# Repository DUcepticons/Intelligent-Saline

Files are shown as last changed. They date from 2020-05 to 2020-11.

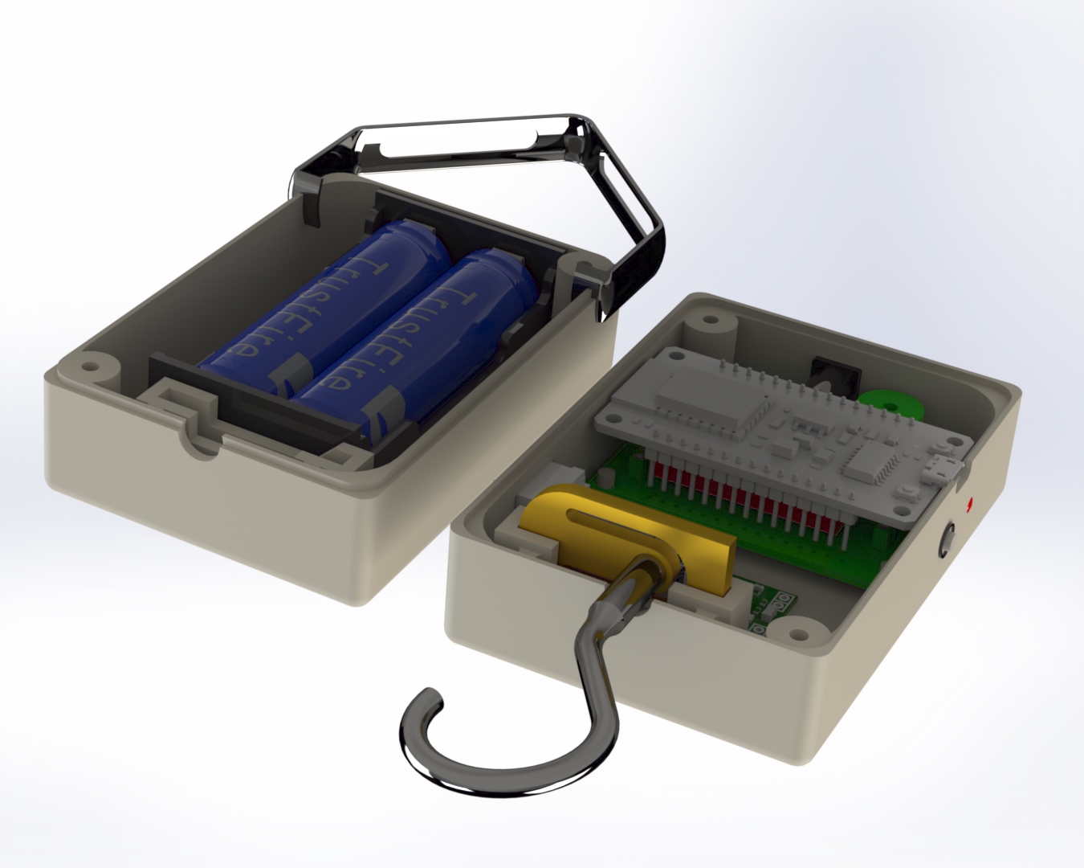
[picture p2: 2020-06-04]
Device Images/Inside_designed.jpg

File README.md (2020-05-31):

# Intelligent-Saline

cmd>> ipconfig
See the server ip address (192.168.0.xxx)

Edit those two NodeMCU code lines:
const char *host = "192.168.0.xxx"; 
String Link = "http://192.168.0.xxx:8000/receive/";

Instruction to run server (USE IP OTHERWISE NODEMCU DATA WON'T BE RECEIVED): python manage.py runserver 192.168.0.xxx:8000
In a browser go to - 192.168.0.xxx:8000
Voilla!! Here you go....

Existing login: 
ducepticons
saline123

To Create a new user: python manage.py createsuperuser

django 3.0.3

To use database in command shell:
going to command shell>> python manage.py shell
>> from main.models import patient
>> object = patient.objects.all()

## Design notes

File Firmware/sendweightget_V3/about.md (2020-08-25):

V3 is updated with external flow blocker.

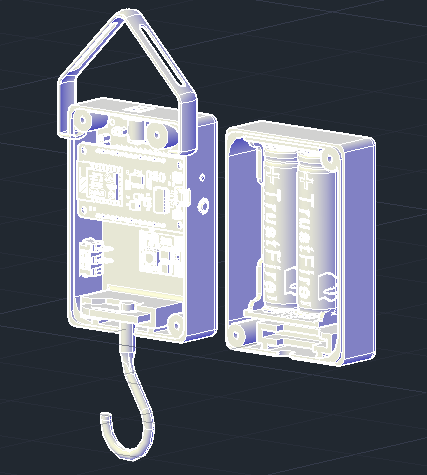
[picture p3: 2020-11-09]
Autocad Compatible/Autocad Images/Product/Device Only/conceptual.png

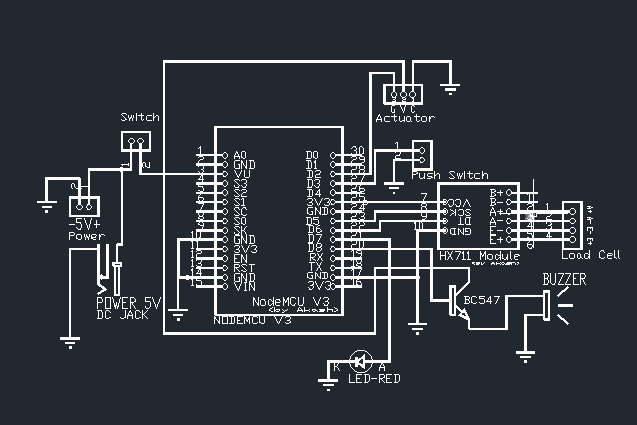
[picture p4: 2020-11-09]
Autocad Compatible/Autocad Images/PCB/schematic.png

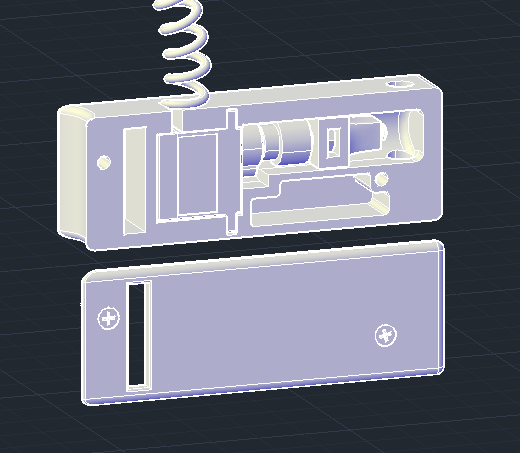
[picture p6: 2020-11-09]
Autocad Compatible/Autocad Images/Product/Flow Controller/Conceptual.png

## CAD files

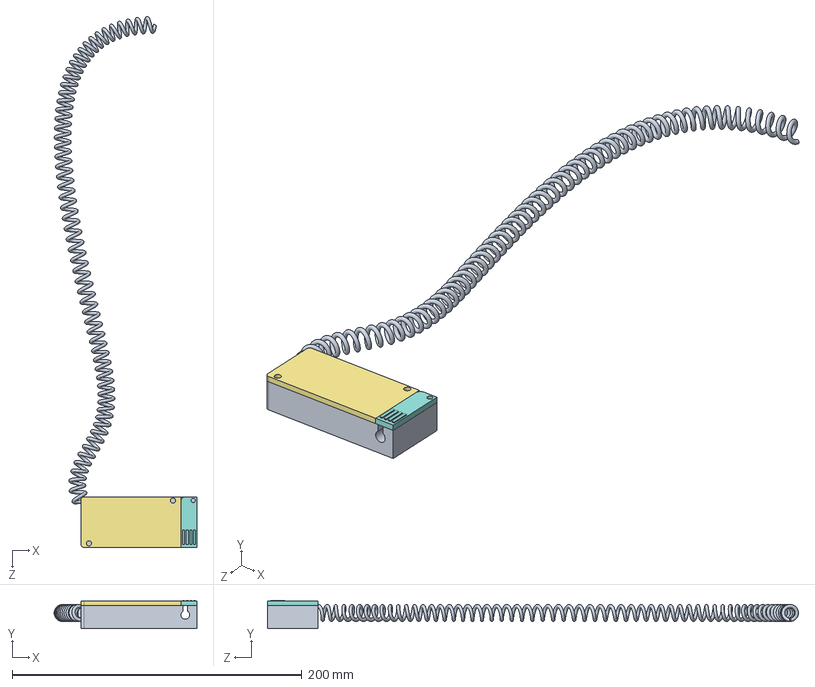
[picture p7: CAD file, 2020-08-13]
Product Design/V2/flow blocker/Version1 Flow blocker/Flow blocker assembly.SLDASM
98.6 x 19.5 x 366.6 mm
flow blocker
Servo-MG90S
pan cross head_am
hex nut style 1_am
servo bolt connector
press
upper cover
pipe cover
Spiral-cord

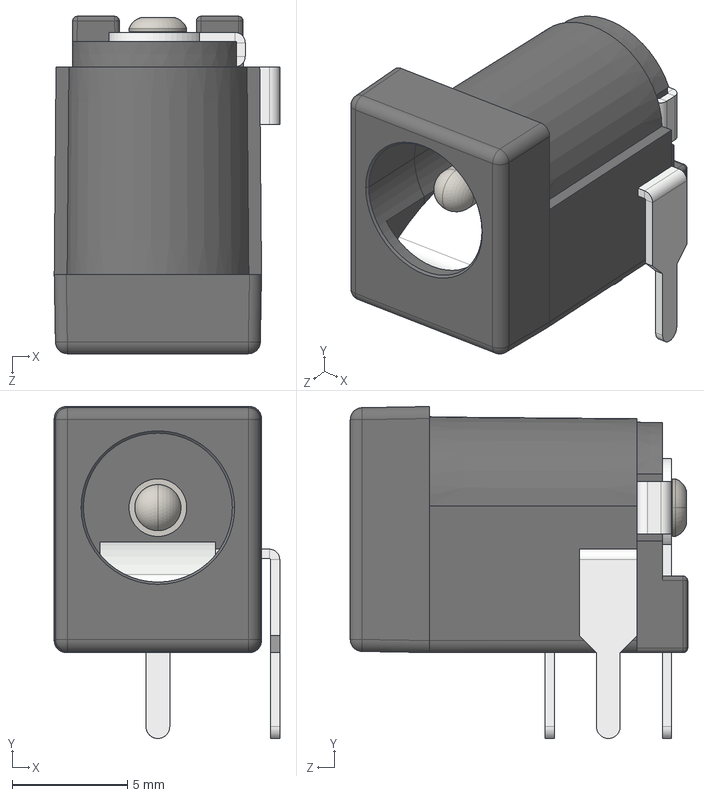
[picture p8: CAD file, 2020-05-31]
Product Design/V2/dc-power-jack-5-5mm-x-2-1mm-2-54mm-pitch-1.snapshot.5/DC Power Jack 5.5mm x 2.1mm.STEP
9.77 x 14.4 x 14.6 mm

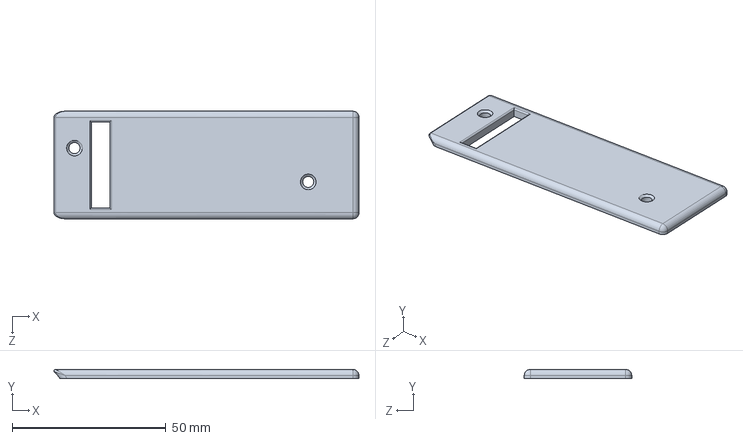
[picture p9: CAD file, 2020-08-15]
Product Design/V2/flow blocker/upper cover.SLDPRT
99.2 x 3.00 x 35.0 mm

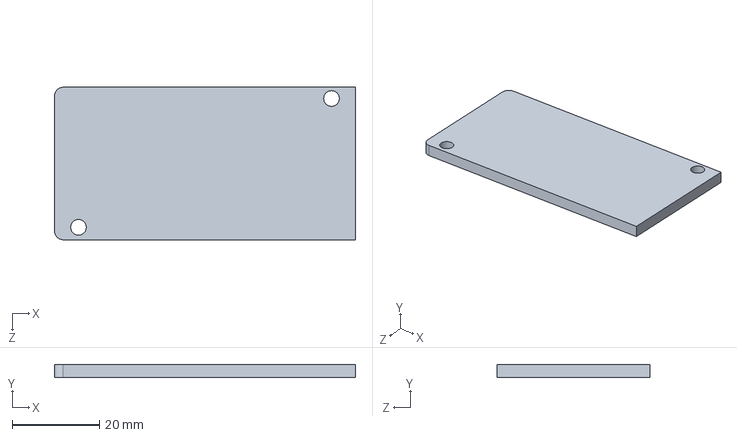
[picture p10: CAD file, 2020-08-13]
Product Design/V2/flow blocker/Version1 Flow blocker/upper cover.SLDPRT
69.0 x 3.00 x 35.0 mm

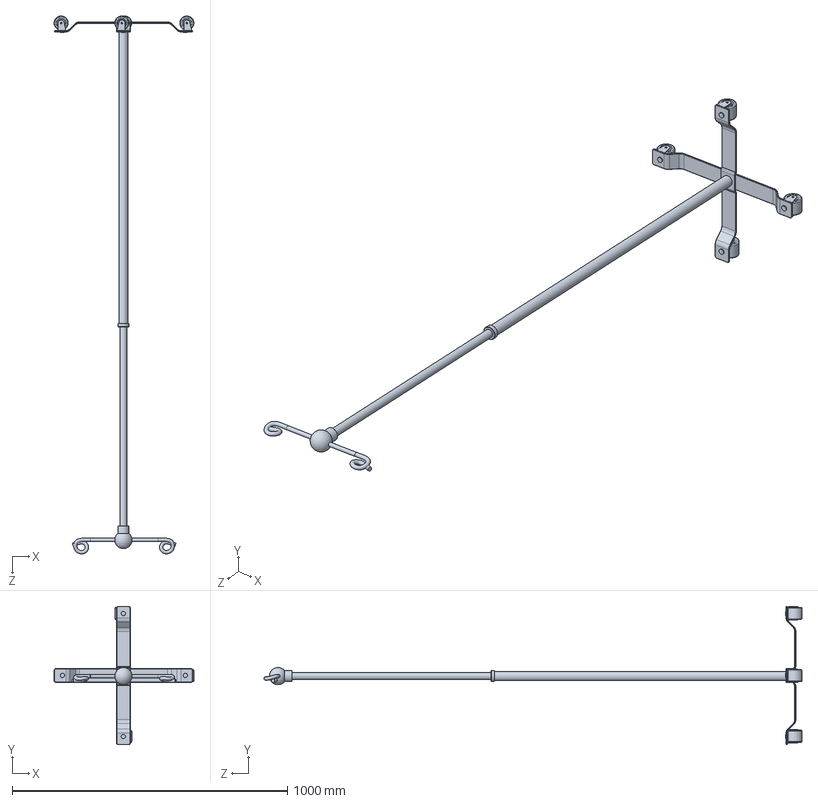
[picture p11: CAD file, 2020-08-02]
Product Design/V2/IV Stand.SLDPRT
508.6 x 502.9 x 1955.7 mm

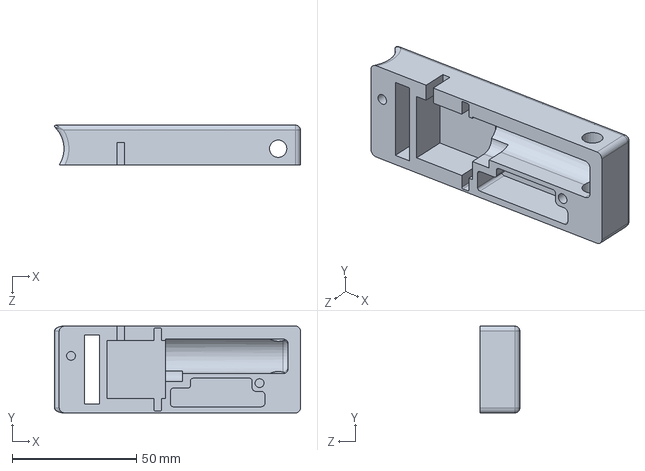
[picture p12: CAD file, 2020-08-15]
Product Design/V2/flow blocker/flow blocker.SLDPRT
99.2 x 35.0 x 16.0 mm

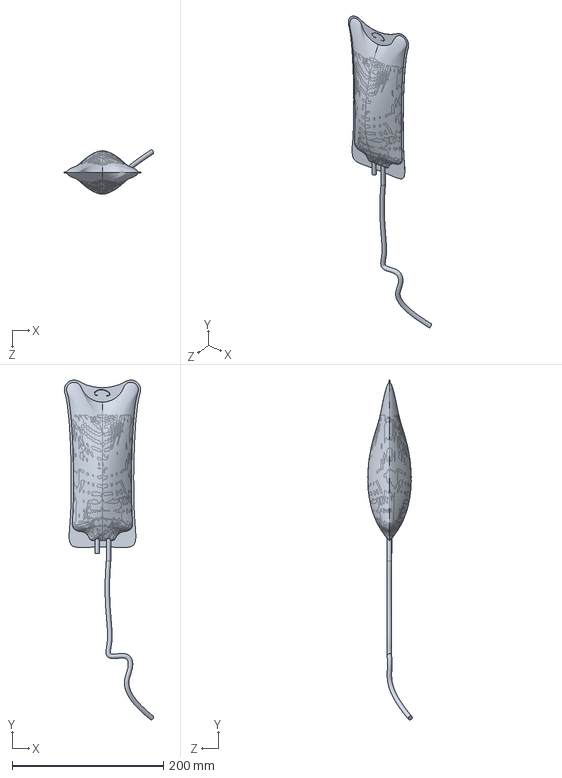
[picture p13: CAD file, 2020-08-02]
Product Design/V2/saline bag.SLDPRT
118.3 x 449.9 x 58.9 mm

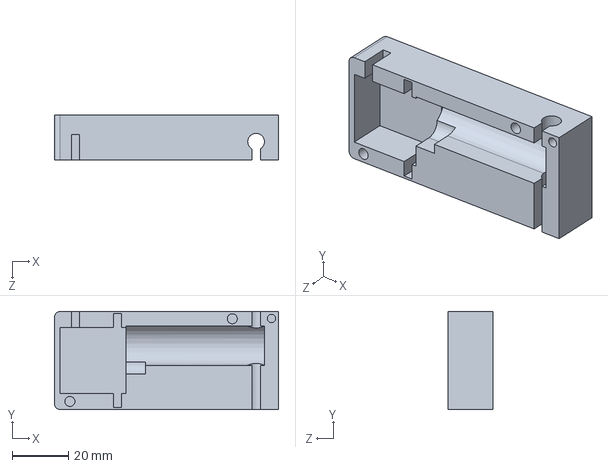
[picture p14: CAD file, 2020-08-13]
Product Design/V2/flow blocker/Version1 Flow blocker/flow blocker.SLDPRT
80.0 x 35.0 x 16.0 mm

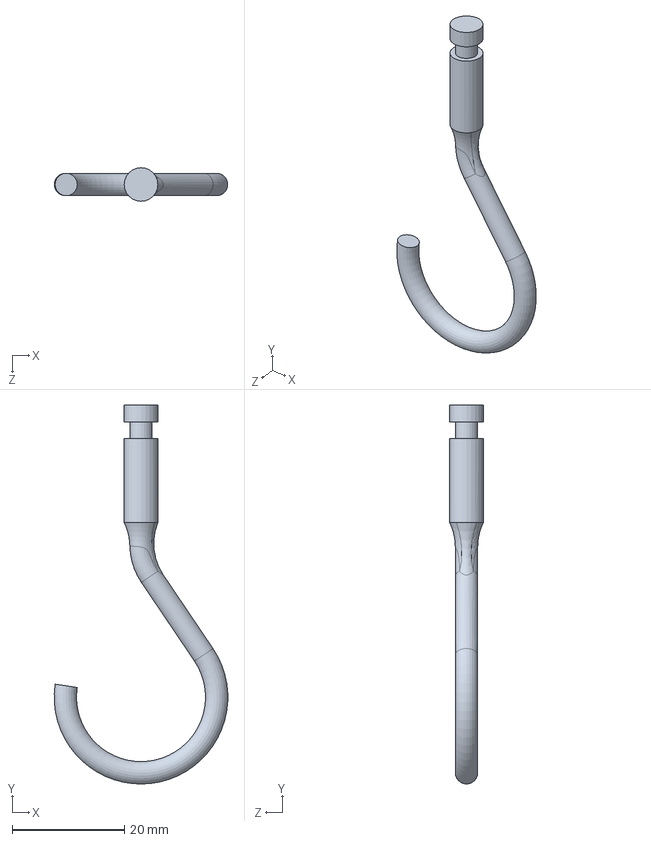
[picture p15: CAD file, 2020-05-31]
Product Design/V2/hook.SLDPRT
31.0 x 67.6 x 6.00 mm

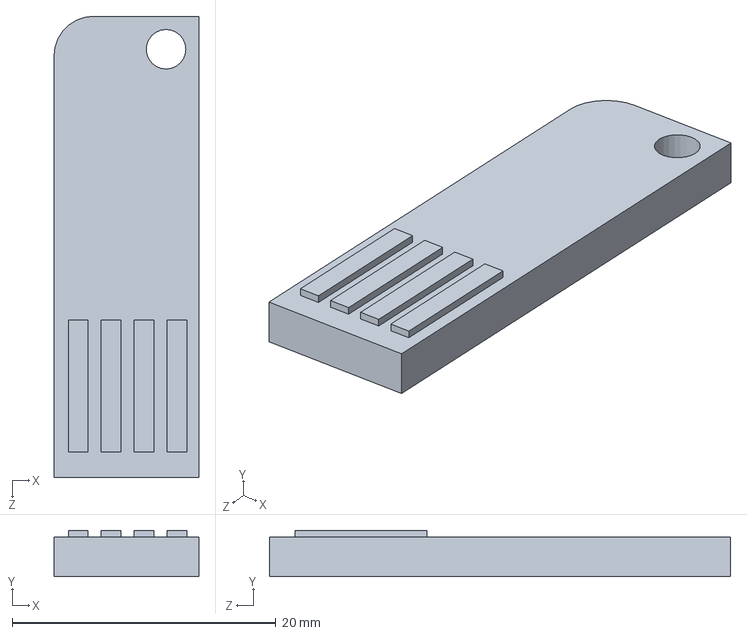
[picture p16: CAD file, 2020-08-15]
Product Design/V2/flow blocker/pipe cover(not used).SLDPRT
11.0 x 3.50 x 35.0 mm

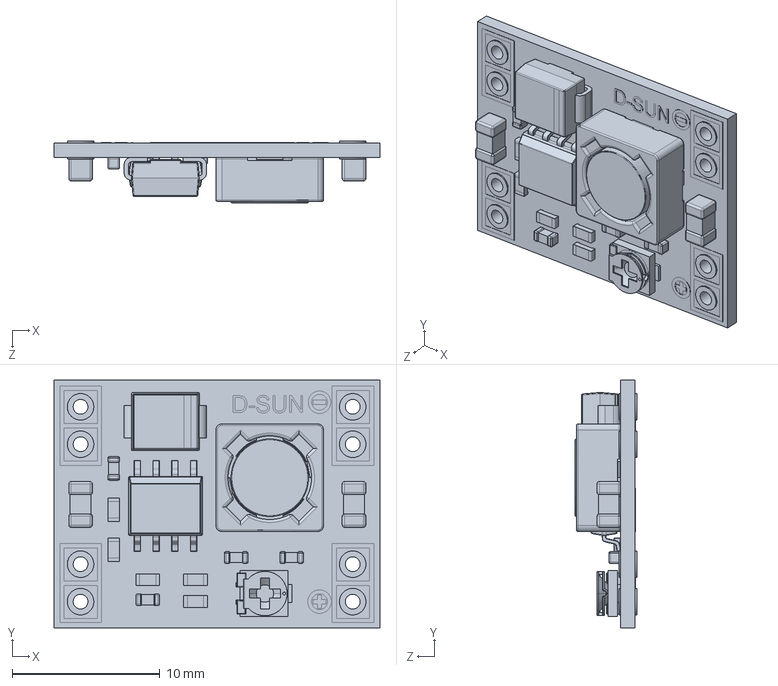
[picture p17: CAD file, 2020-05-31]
Product Design/V2/voltage-regulator.SLDPRT
22.1 x 16.8 x 4.19 mm

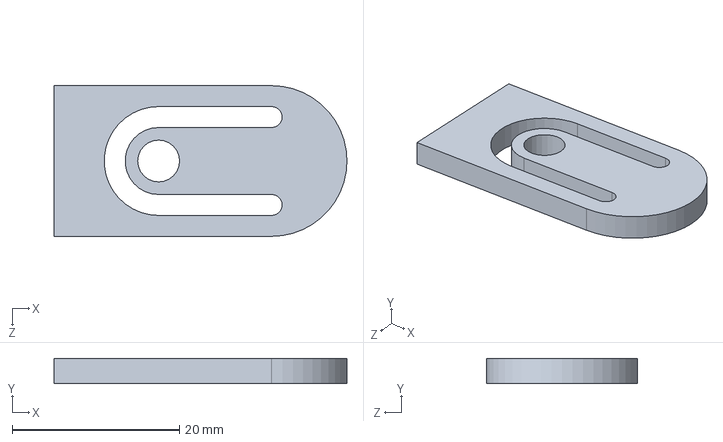
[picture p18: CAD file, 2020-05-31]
Product Design/V2/load cell.SLDPRT
35.0 x 3.00 x 18.0 mm

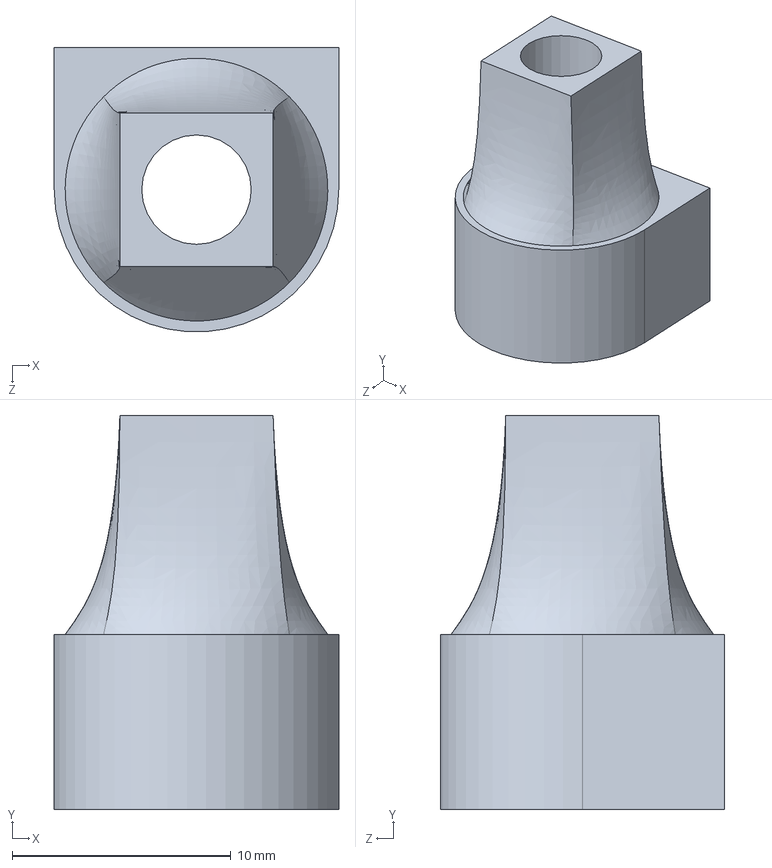
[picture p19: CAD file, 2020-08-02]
Product Design/V2/flow blocker/Version1 Flow blocker/press.SLDPRT
13.0 x 18.0 x 13.0 mm

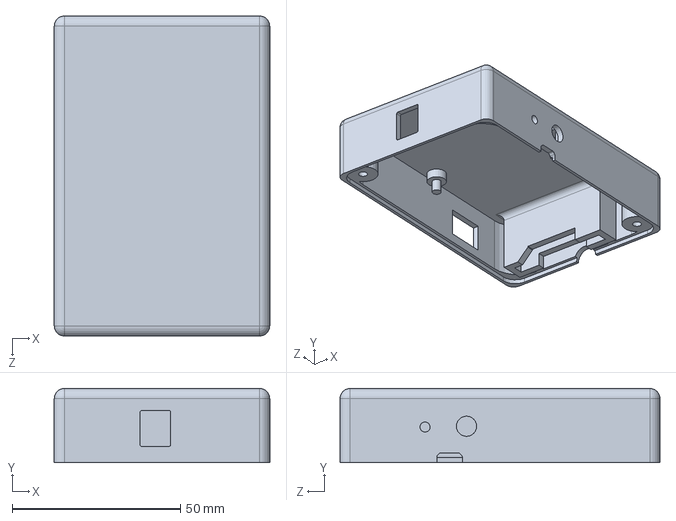
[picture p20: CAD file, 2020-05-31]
Product Design/V2/upper_body.SLDPRT
64.0 x 22.0 x 95.0 mm

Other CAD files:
Autocad Compatible/PCB Design/schematic.dwg
Autocad Compatible/PCB Design/pcb_bottomLayer.dwg
Autocad Compatible/PCB Design/pcb_topLayer.dwg
Product Design/V2/flow blocker/Version1 Flow blocker/pipe cover.SLDPRT
Product Design/V1/18650-retainers-1.snapshot.4/18650 1x Holder - Compressed.stp
Product Design/V1/18650-retainers-1.snapshot.4/18650 1x Holder.stp
Product Design/V1/18650-retainers-1.snapshot.4/BC2-3AE.stp
Product Design/V1/18650-retainers-1.snapshot.4/BK-18650-PC2.stp
Product Design/V1/18650-retainers-1.snapshot.4/BK-18650-PC4.stp
Product Design/V1/18650-retainers-1.snapshot.4/BK-18650-PC6.stp
Product Design/V1/18650-retainers-1.snapshot.4/BK-18650-PC8.stp
Product Design/V1/18650-retainers-1.snapshot.4/keystone_1042-Mod.stp
Product Design/V1/2-Pin ON-OFF Switch.SLDPRT
Product Design/V1/TR18650.SLDPRT
Product Design/V1/batt-case-18650.SLDPRT
Product Design/V1/hook.SLDPRT
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

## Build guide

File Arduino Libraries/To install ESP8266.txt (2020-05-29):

1 .
Arduino >> File >> Preferences
In additional board manager URLs pase : http://arduino.esp8266.com/stable/package_esp8266com_index.json

2.
Tools >> Board >> Board Manager >> search "esp8266" >> install (suitable one)

3.
Tools >> Select Board >> NodeMCU 1.0

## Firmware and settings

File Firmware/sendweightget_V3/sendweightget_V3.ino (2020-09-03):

#include <ESP8266WiFi.h>
#include <WiFiClient.h> 
#include <ESP8266WebServer.h>
#include <ESP8266HTTPClient.h>
#include <HX711.h>
#include<Servo.h>
#include <EEPROM.h>

String DEV_ID = "DEV00002";                                   //Input the device id here
const char *ssid = "DUcepticons";                                 //ENTER YOUR WIFI SETTINGS
const char *password = "webpass321";

//Web/Server address to read/write from 
const char *host = "192.168.0.102"; 
String Link = "http://192.168.0.102:8000/receive/";

char eepromStatus;
int EEPROMaddress = 0; //Reading from address 0x00

int critical_value = 15;
int very_critical_value = 10;
int flow_block_value = 5;
const int SCALE_DOUT_PIN = D6;
const int SCALE_SCK_PIN = D5;
const int Buzzer = D8;
const int LED = D7;
const int Push_button = D3;
const int ServoPin = D2;
int push_button_state = 0;

int flag = 0;
float initial_saline_weight;
float weight = 0;
int count = 0;

int sendPercentage=100;
int previous_sendPercentage =0;
String payload;
float full_bag_weight;
float package_weight;

String previousOnOff_status = "1";

void buzzer_alarm(int rate);        // input how many times to beep in a second
void buzzer_stop();
void buzzer_indication(int times, int Delay);  //input how many times to beep buzzer and stop

HX711 scale(SCALE_DOUT_PIN, SCALE_SCK_PIN);
void Lock(int Speed, int Delay);//Flow block function
void Open(int Speed, int Delay);//Flow open function

Servo servo;      // Flow blockeer servo declare
//=======================================================================
//                    Power on setup
//=======================================================================

void setup() {
  Serial.begin(115200);
  EEPROM.begin(512);  //Initialize EEPROM
  scale.set_scale(45);// <- set here calibration factor!!!
  scale.tare();
  pinMode(Buzzer,OUTPUT);
  pinMode(LED,OUTPUT);
  pinMode(Push_button,INPUT_PULLUP);
  
  digitalWrite(Buzzer,HIGH);
  digitalWrite(LED,HIGH);
  delay(1000);
  digitalWrite(Buzzer,LOW);
  digitalWrite(LED,LOW);

   
  weight = scale.get_units(1);
  float new_weight = 0;
  int not_ok = 1;
  

  //Wait and slow beepiing untill saline is On device hook
  Serial.println("Waiting for saline.....");
 
  while(true)
  {
    new_weight = scale.get_units(1);
    if(abs(new_weight-weight) >250)break;   //250 depends on variety of saline pack can be used in this device
    buzzer_indication(1,1000);
    weight = new_weight;
  }
Serial.println("Saline on device");
weight = 0;

Serial.println("Saline recognizing...");
//automatic weight recognition
  while(true)
  {
    new_weight = abs(scale.get_units(1));
    Serial.println(new_weight);
    if(abs(new_weight-weight) <10 && count>=15)
    {
      if(new_weight > 300 && new_weight < 800)
      {
          initial_saline_weight = 500;          
          //not_ok = 0;
          break;
      }
      else if(new_weight > 800 && new_weight < 1500)
      {
          initial_saline_weight = 1000;
          //not_ok = 0;
          break;
      }
    }
    weight = new_weight;
    count++;
  }
  count=0;
Serial.println("Saline recognized as "+ String(initial_saline_weight));
  


  WiFi.mode(WIFI_OFF);        //Prevents reconnection issue (taking too long to connect)
  delay(1000);
  WiFi.mode(WIFI_STA);        //This line hides the viewing of ESP as wifi hotspot
  
  WiFi.begin(ssid, password);     //Connect to your WiFi router
  Serial.println("");

  Serial.print("Connecting");
  // Wait for connection
  while (WiFi.status() != WL_CONNECTED) {
    delay(300);
    flag ^= 1;
    digitalWrite(Buzzer,flag);
    Serial.print(".");
  }

  //If connection successful show IP address in serial monitor
  Serial.println("");
  Serial.print("Connected to ");
  Serial.println(ssid);
  Serial.print("IP address: ");
  Serial.println(WiFi.localIP());  //IP address assigned to your ESP


  full_bag_weight = abs(scale.get_units(1));
  package_weight = abs(full_bag_weight - initial_saline_weight);
  Serial.println("full_bag_weight: "+ String(full_bag_weight));
  Serial.println("package_weight: "+ String(package_weight));
  buzzer_stop();

  servo.attach(ServoPin);

  char eepromStatus = EEPROM.read(EEPROMaddress);
  
//if it was previously blocked, turn it on
  if (eepromStatus == '1'){
    Open(110, 4500);
    Serial.println("Saline flow Open...");
    EEPROM.write(EEPROMaddress, '0');    //Write character 0, meaning flow is turned on   
  }
}

//=======================================================================
//                    Main Program Loop
//=======================================================================




void loop() {

  weight = abs(scale.get_units(1)) - package_weight;
  Serial.println("Weight: "+ String(weight, 2));
  
  HTTPClient http;    //Declare object of class HTTPClient

 //GET Data
  
  sendPercentage= (weight/initial_saline_weight)*100 ;
  
  //Keeping in range of 0-100
  if(sendPercentage<0)sendPercentage=0;
  if(sendPercentage>100)sendPercentage=100;
  
  Serial.println(sendPercentage);

  String postData = DEV_ID + "," + String(sendPercentage);
  Serial.print(postData);
  Serial.print(Link);
  http.begin(Link);     //Specify request destination
  
  int httpCode = http.POST(postData);            //Send the request
  payload = http.getString();    //Get the response payload  //returns two digit value(ex. 50/51/60/61) First value for mute button(6=mute pressed, 5= default), 2nd value for saline on/off button(1=ON, 0=OFF)

  Serial.println(httpCode);   //Print HTTP return code
  Serial.println("payload" + payload);    //Print request response payload
  http.end();  //Close connection

//==========================================
//Flow ON/OFF function
//if toggled OFF
if((String)payload[1] == "0" && previousOnOff_status != (String)payload[1]){
  Lock(70, 4500);
  Serial.println("Saline flow Blocked!!!");
  eepromStatus = '1';
}
//if toggled ON
if((String)payload[1] == "1" && previousOnOff_status != (String)payload[1]){
  Open(110, 4500);
  Serial.println("Saline flow Open...");
  eepromStatus = '0';
}
previousOnOff_status = (String)payload[1];

/*
//debugging
if (sendPercentage <=critical_value && very_critical_value<sendPercentage)
{
  Serial.println("State : Critical");
}
else if (sendPercentage <=very_critical_value)
{
  Serial.println("State : Very Critical");
}
else
{
  Serial.println("State : Normal");
}
*/

//push_button_state change for entering 1-10%zone from 11-20%zone
if ((previous_sendPercentage <=critical_value  && previous_sendPercentage >very_critical_value) && (sendPercentage<=very_critical_value))
{
  push_button_state = 0;
}
previous_sendPercentage=sendPercentage;


//Push button read
  int button = digitalRead(Push_button);    // it reads 0 for press, 1 otherwise
  if (button == 0)Serial.println("button pressed");
  if((sendPercentage <= critical_value) && (button == 0 || (String)payload[0] == "6"))push_button_state = 1;   //when percentage under critical and mute button pressed
  //Serial.println(push_button_state);                                                              //payload returns 6 if mute button pressed
  Serial.println("\n\n");

  
//critical and very_critical saline level indication
  if (push_button_state == 0)
  {
    count++;
    if(sendPercentage <= critical_value  && very_critical_value < sendPercentage  && count>  6)
      {
        buzzer_indication(1,500);
        count = 0;
      }
    else if(sendPercentage <= very_critical_value  && count>  4)
      {
        buzzer_indication(3,175);
        count = 0;
      }
  }
if (sendPercentage >=critical_value)
{
  delay(1000);
  push_button_state = 0;
}

//flow block whenever percentage under flow_block_value
if (sendPercentage <= flow_block_value && eepromStatus != '1'){
   //if percentage<= flow_block_value and if flow was not blocked previously
  digitalWrite(Buzzer,HIGH);
  digitalWrite(LED,HIGH);
  Lock(70, 4500);
  Serial.println("Saline flow Blocked!!!"); 
  digitalWrite(Buzzer,LOW );
  digitalWrite(LED,LOW );
  EEPROM.write(EEPROMaddress, '1');    //Write character 1, meaning flow is blocked

}
  
}
//=======================================================================


void buzzer_alarm(int rate){
  digitalWrite(Buzzer,HIGH);
  delay(500/rate);
  digitalWrite(Buzzer,LOW );
  delay(500/rate);
}

void buzzer_stop(){
 digitalWrite(Buzzer,LOW );
}
void buzzer_indication(int times, int Delay){
  for( int i=0;i<times;i++)
  {
    digitalWrite(Buzzer,HIGH);
    digitalWrite(LED,HIGH);
    delay(Delay);
    digitalWrite(Buzzer,LOW );
    digitalWrite(LED,LOW );
    delay(Delay);
  }
}

//Flow block function
void Open(int Speed, int Delay){
  //When speed==90;stop
  //When speed>90;clockwise
  //When speed<90;anticlockwise
  servo.write(Speed);
  delay(Delay);
  servo.write(90);
}

//Flow open function
void Lock(int Speed, int Delay){
  //When speed==90;stop
  //When speed>90;clockwise
  //When speed<90;anticlockwise
  servo.write(Speed);
  delay(Delay);
  servo.write(90);
}

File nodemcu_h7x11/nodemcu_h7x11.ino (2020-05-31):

#include <HX711.h>

// Scale Settings
const int SCALE_DOUT_PIN = D6;
const int SCALE_SCK_PIN = D5;

HX711 scale(SCALE_DOUT_PIN, SCALE_SCK_PIN);

void setup() {
  Serial.begin(115200);
  //scale.begin(SCALE_DOUT_PIN, SCALE_SCK_PIN);
  scale.set_scale(45);// <- set here calibration factor!!!  45 works well
  scale.tare();
}

void loop() {
  float weight = scale.get_units(1);
  Serial.println(String(weight, 2));
  delay(200);
}

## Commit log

2019-08-11 number of patients
2019-08-11 successful ajax and critical patient
2019-09-06 onek kaj
    green-red color change
    homepage dynamic
    navbar hamburger to cross animation
    h7x11 code add with nodemcu
    graph plot excel
    [Time vs Weight Graph.xlsx]
2019-12-09 device page update
2019-12-18 arduino code change
2019-12-20 on off button working
2020-01-11 PCB & Housing Design
    [18650 1x Holder - Compressed.stp, 18650 1x Holder.stp, 2-Pin ON-OFF Switch.SLDPRT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]
2020-01-11 pcb update
2020-01-11 product update
    [2-Pin ON-OFF Switch.SLDPRT, 2-Pin ON-OFF Switch.STEP, load cell.SLDPRT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]
2020-03-06 footer, buzzer button and loginpage
2020-03-09 Updated arduino code and some other stuff
2020-05-28 PCB V2 created
2020-05-29 Design Update
    [18650 1x Holder - Compressed.stp, 18650 1x Holder.stp, 2-Pin ON-OFF Switch.SLDPRT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]
2020-05-31 Remote mute button fix
    [sendweightget_V2.ino]
2020-05-31 Added patient ID, Device ID is now DEV#######
    Device ID is now DEV#######
2020-06-01 navbar and devices page edit
2020-06-04 Case open render
2020-06-04 Fixed no devices error
2020-08-02 flow blocker added
    [Flow blocker assembly.SLDASM, IV Stand.SLDPRT, Servo-MG90S.SLDPRT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]
2020-08-15 Flow blocker Design Update
    [Flow blocker assembly.SLDASM, Servo-MG90S.SLDPRT, flow blocker.SLDPRT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]
2020-08-25 Saline ON/OFF button working
2020-09-04 Device images added
2020-11-03 pcb new workspace
2020-11-03 Autocad files created
    [pcb_bottomLayer.dwg, pcb_topLayer.dwg, schematic.dwg]
2020-11-09 Flow controller image added
